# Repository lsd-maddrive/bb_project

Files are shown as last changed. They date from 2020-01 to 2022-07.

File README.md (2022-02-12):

# BB-ka project

<div align="center">






</div>

Проект под командной разработкой, направленный на создание прикольной зверюхи a-ля BB-8 Звёздных войн, но с блэкджеком и силовыми драйверами.

<p align=center>
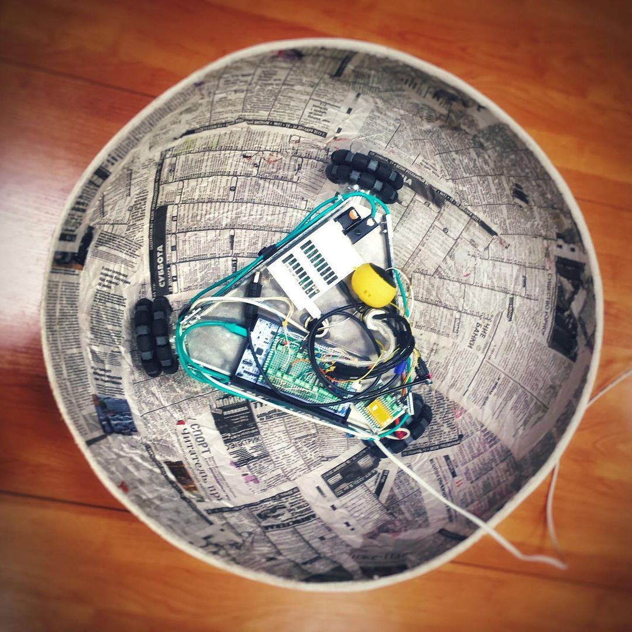
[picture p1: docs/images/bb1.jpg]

</p>

## Системные требования

- Версия Python: 3.8
- Операционная система: Ubuntu 20.04

## Настройка проекта

1. Установка 'make'

    * Windows - Установите [chocolatey](https://chocolatey.org/install) и установите 'make' командой:
    ```
    choco install make
    ```
    * Linux
    ```
    sudo apt-get install build-essential
    ```

2. Установите Python 3.8
    * Windows - Установите с [официального сайта](https://www.python.org/downloads/)
    * Linux
    ```
    sudo apt install python3.8-dev
    ```
3. Установите `poetry`
   * Windows - Используйте [официальные инструкции](https://python-poetry.org/docs/#windows-powershell-install-instructions) или команду powershell:
   ```
   (Invoke-WebRequest -Uri https://raw.githubusercontent.com/python-poetry/poetry/master/get-poetry.py -UseBasicParsing).Content | python -
   ```
   * Linux
    ```
    make poetry-download
    ```
4. Установите форматтеры и другие инструменты для разработки
    ```
    make tools-install
    ```
5. При работе с Jupyter-ноутбуками используйте виртуальное окружение, созданное `poetry` - `.venv`

## Полезные ссылки

* [F767ZI Reference manual (RM)](http://www.st.com/content/ccc/resource/technical/document/reference_manual/group0/96/8b/0d/ec/16/22/43/71/DM00224583/files/DM00224583.pdf/jcr:content/translations/en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)
* [F767ZI Datasheet (DS)](http://www.st.com/content/ccc/resource/technical/document/datasheet/group3/c5/37/9c/1d/a6/09/4e/1a/DM00273119/files/DM00273119.pdf/jcr:content/translations/en.DM0027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)
* [F767ZI Nucleo pinout](https://os.mbed.com/platforms/ST-Nucleo-F767ZI/)
---
* [F767ZI Alternate functions](http://www.st.com/content/ccc/resource/technical/document/datasheet/group3/c5/37/9c/1d/a6/09/4e/1a/DM00273119/files/DM00273119.pdf/jcr:content/translations/en.DM0027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)
* [F767ZI Pins assignment (+analogs)](http://www.st.com/content/ccc/resource/technical/document/datasheet/group3/c5/37/9c/1d/a6/09/4e/1a/DM00273119/files/DM00273119.pdf/jcr:content/translations/en.DM0027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)
* [F767ZI Timer triggers](http://www.st.com/content/ccc/resource/technical/document/reference_manual/group0/96/8b/0d/ec/16/22/43/71/DM00224583/files/DM00224583.pdf/jcr:content/translations/en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)

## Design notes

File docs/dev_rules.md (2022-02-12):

Привет, разработчик!
Здесь будут перечислены некоторые правила, которых стоит придерживаться для создания единого стиля разработки =)

* Оформление функций в соответствии со стилем `CamelCase` [`breakSensorIsPressed()`] или через `snake_case` [`break_sensor_is_pressed()`].

* Комментарии к функциям устанавливаются в соответствии с
[Doxygen стилем](https://www.rosettacommons.org/docs/latest/development_documentation/tutorials/doxygen-tips) / [Еще](https://www.stack.nl/~dimitri/doxygen/manual/commands.html)
Например
```c++
/*
 * @brief       This function makes something good
 * @param [in]  val  Motor power value [0-100]
 */

```
или
```c++
/**
 * Brief description of method
 * @pre
 *    Any preconditions that this method requires
 * @post
 *    Any postconditions that result because of this method
 * @param [0, n-1] paramName
 *    Brief description of parameter
 * @return
 *    Brief description of return value
 * @throw
 *    An EXPLICIT throw specification - including which guarantee it offers (basic, strong, nothrow)
 *    and WHY the various exceptions may be thrown.
 */
```

* Комментарии к переменным можно снабжать однострочными комментариями, желательно на строке, предшествующей определению переменной
```c++
/* Encoder tick count, should be limited by range [-1000; 1000] */
int16_t ticks = 0;

```

* Каждый модуль должен снабжаться заголовочным файлом с набором данных, которые отображают, что можно использовать в других модулях (открытые прототипы и структуры)

```c++
/* Header content */
#ifndef HEADER_NAME_H_
#define HEADER_NAME_H_

typedef struct
{
    /* Absolute value of accelerometer range */
    uint32_t accel_range;

    /* Absolute value of gyroscope range */
    uint32_t gyro_range;

} imu_conf_t;

/* 32 bits - *100 multiplier encoded float value */
/* 3245 <- 32.45 accel value */
typedef int32_t imu_accel_val_t;

/**
 * @brief
 *      Initialize and start IMU driver
 * @param   conf
 *      Pointer to configuration structure
 * @return
 *      EOK     - ok
 *      EFAULT  - failed to initialize
 */
int imu_start(imu_conf_t *conf);

/**
 * @brief
 *      Get IMU acceleration value by axis X
 * @param   out_x_val
 *      Referenced value of X acceleration to be written
 * @return
 *      EOK     - ok
 *      EFAULT  - failed calculation
 *      EIO     - reading failed
 */
int imu_get_accel_x(imu_accel_val_t *out_x_val);

...

#endif // HEADER_NAME_H_
```

* Отступы (indents) должны иметь размер 4 пробела (не табуляция) [редакторы могут заменять нажатие Tab на необходимый отступ]

* Определение типов задается по шаблону `<название типа>_t`, например, `breakPower_t`

* Любой разрабатываемый модуль должен проходить стадию разработки, тестирования и добавления в основную ветку (develop). В ветку мастер (master) добавляются только версии со 100% рабочими изменениями при согласии всех разработчиков.

* Тестирование должно проводиться в отдельно разработанном приложении с минимальным количеством кода при максимально использовании модуля. Постарайтесь как можно разносторонне проверить модуль =). Для примера, проверка сенсора может производиться путем периодического чтения данных и вывода в последовательный порт форматированным выводом. Само тестирование предполагает изменение условий сенсора и проверка вывода.

* В комментарии к коммиту указывается название ветки или название разрабатываемого модуля. Для общих исправлений используется тэг `[common]`.
```bash
git commit -am '[frontWheel]: New prototype for: int direction_get_value(dirVal_t *out_value);'

```

* При закрытии issue необходимо указывать коммент, в котором были сделаны последние изменения по теме issue.
```bash
git commit -am '[directionDriver]: Fixed #34'

```
* При разрешении issue необходимо присваивать работу над ним себе (если оно ранее уже не было присвоено), тем самым вы обозначите, что вы берётесь зе его исправление. Кроме того, по возможности необходимо классифицировать его с помощью лейбла:
- enchancement (нововведедние / предложение)
- bug
- help wanted
- duplicate
- good first issue
- invalid

---
Просто некоторые заметки:

* Хороший гайд по ведению веток: http://nvie.com/posts/a-successful-git-branching-model

* Для добавления собственного модуля необходимо добавить указания `.c` файлов в project.mk.

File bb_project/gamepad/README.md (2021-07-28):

# How to deal with Xbox joystick 

1. Check available software

```bash
sudo apt-get update
sudo apt-get upgrade
```

2. Install xow driver 

* 2.1. Install libusb

```bash
sudo apt-get install libusb-1.0-0-dev
```

* 2.2. Install cabextract

```bash
sudo apt-get install cabextract
```

* 2.3. Follow the original [README](https://github.com/medusalix/xow)

3. Install all required modules

```bash
pip3 install -r requirements.txt
```

4. Run python-script 

```bash
python3 gamepad.py 
```

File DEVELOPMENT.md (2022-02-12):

# Development guide

This is guide how to prepare development environment and use main tools

## Table of contents

- [Table of contents](#table-of-contents)
- [Preparations](#preparations)
- [Optional setup steps](#optional-setup-steps)
- [Some known issues](#some-known-issues)

## Preparations

1. Install make
    - Windows:

        Install [chocolatey](https://chocolatey.org/install) and install `make` with command:

    ```powershell
    choco install make
    ```

    - Linux:

    ```bash
    sudo apt-get install build-essential
    ```

1. Install python 3.8
    - Windows

        Install with [official executable](https://www.python.org/downloads/)

    - Linux

    ```bash
    sudo apt install python3.8-dev
    ```

1. Install poetry

   - Windows

        Use [official instructions](https://python-poetry.org/docs/#windows-powershell-install-instructions) or use `powershell` command:

    ```powershell
    (Invoke-WebRequest -Uri https://raw.githubusercontent.com/python-poetry/poetry/master/get-poetry.py -UseBasicParsing).Content | python -
    ```

   - Linux

    ```bash
    make poetry-download
    ```

2. Initialize poetry and install `pre-commit` hooks:

```bash
make install
```

[Table of contents](#table-of-contents)

## Optional setup steps

1. Install VSCode Extensions
   - [EditorConfig for VS Code](https://marketplace.visualstudio.com/items?itemName=EditorConfig.EditorConfig)
      Open control panel (Ctrl+P) and enter `ext install EditorConfig.EditorConfig`

1. To initialize generation of Table of Contents from notebook headers we use `nbextension`:

    - `nbextention-toc-install`

    > It is required version nbconvert~=5.6.1 (checked for date 2021-12-29)

    - To export notebook with ToC use next command:

      ```bash
      poetry run jupyter nbconvert --template toc2 --to html_toc --output-dir ./exports <путь до файла>
      ```

      > For example, `poetry run jupyter nbconvert --template toc2 --to html_toc --output-dir ./exports notebooks/example.ipynb`

[Table of contents](#table-of-contents)

## Some known issues

- If you have issues with python version like:

    ```bash
    The currently activated Python version 3.9.7 is not supported by the project (~3.8.0)
    ...
    NoCompatiblePythonVersionFound
    ...
    ```

    Check version of your `python3` binary and make sure you have python3.8 installed.

[Table of contents](#table-of-contents)

Некоторые [правила оформления](https://github.com/serykhelena/bb-8_project/blob/develop/controller_bb_8_driver/docs/dev_rules.md)

## Как изменить код на винде, но прошить через малину

1. После того, как проект собран - запустить батник `move_bin.bat` - он переместит файл `ch.bin` в расшаренную папку (убедитесь, что она есть и креды правильные, иначе доступа не будет).

2. В малине запустить скрипт `pi_load_stm.sh`

```bash
./pi_load_stm.sh
```
[Table of contents](#table-of-contents)

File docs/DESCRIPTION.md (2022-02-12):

# Описание проекта BB-ka

Проект под командной разработкой, направленный на создание прикольной зверюхи a-ля BB-8 из Звёздных войн, но с блэкджеком и силовыми драйверами.

<p align=center>

</p>

## Статьи

### 2021

* [Spherical Robot Remote Control Development](https://ieeexplore.ieee.org/document/9460236)
* [Design and Implementations of Spherical Robot Hardware Level](https://ieeexplore.ieee.org/document/9396257)

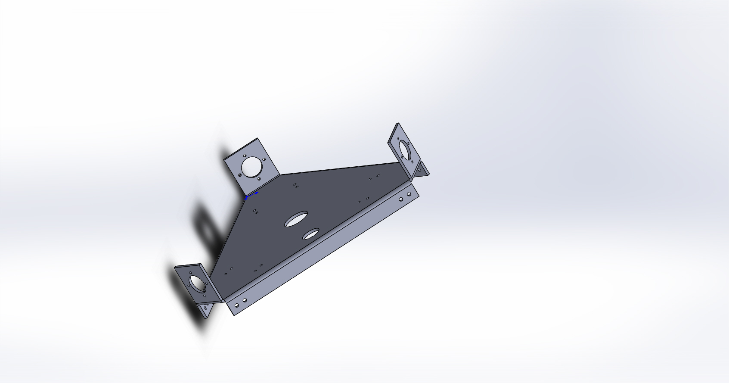
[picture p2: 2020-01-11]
Чертежи/Платформы/Для изготовления/Нижняя платформа.JPG

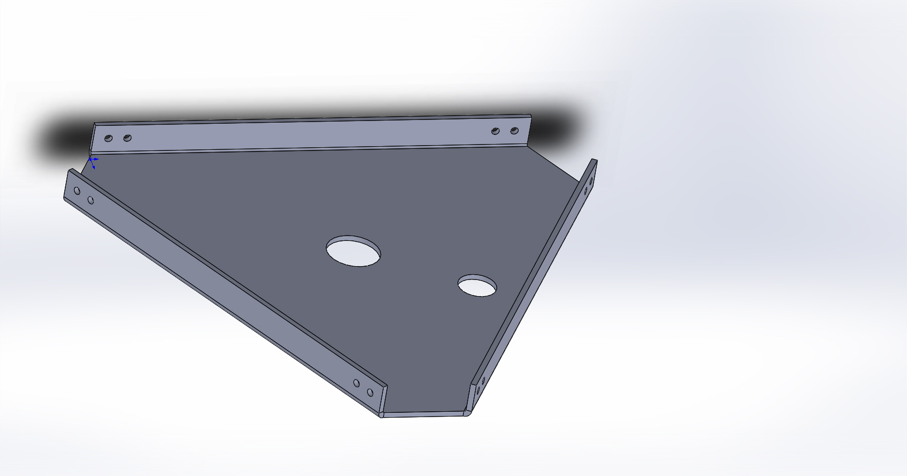
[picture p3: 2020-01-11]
Чертежи/Платформы/Для изготовления/Верхняя платформа.JPG

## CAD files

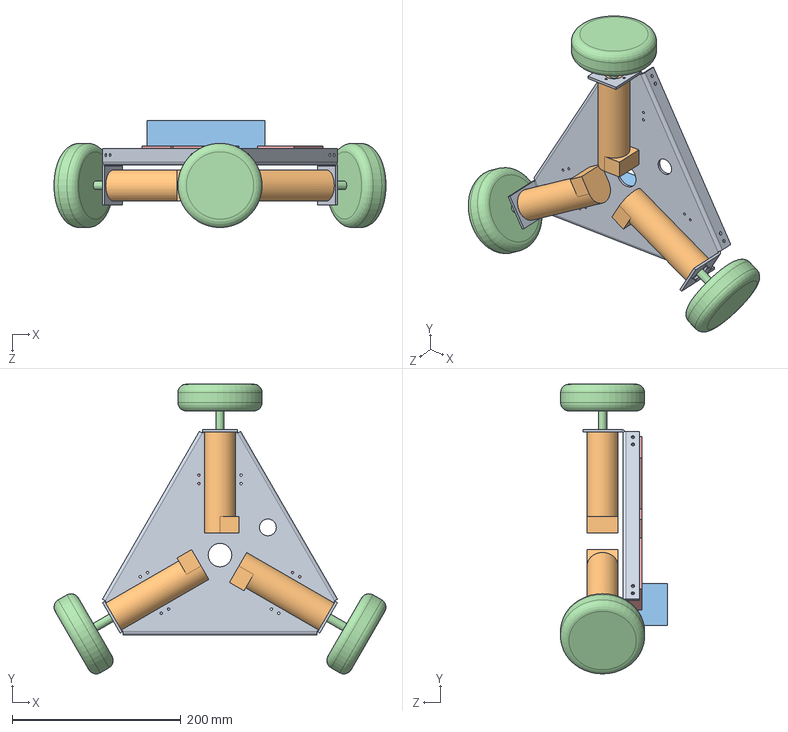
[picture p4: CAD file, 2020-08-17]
Чертежи/Платформы/Сборка1.SLDASM
394.0 x 344.0 x 126.9 mm
Нижняя платформа
Motor x 3
батарейка
Колесо x 3
Драйвер x 3

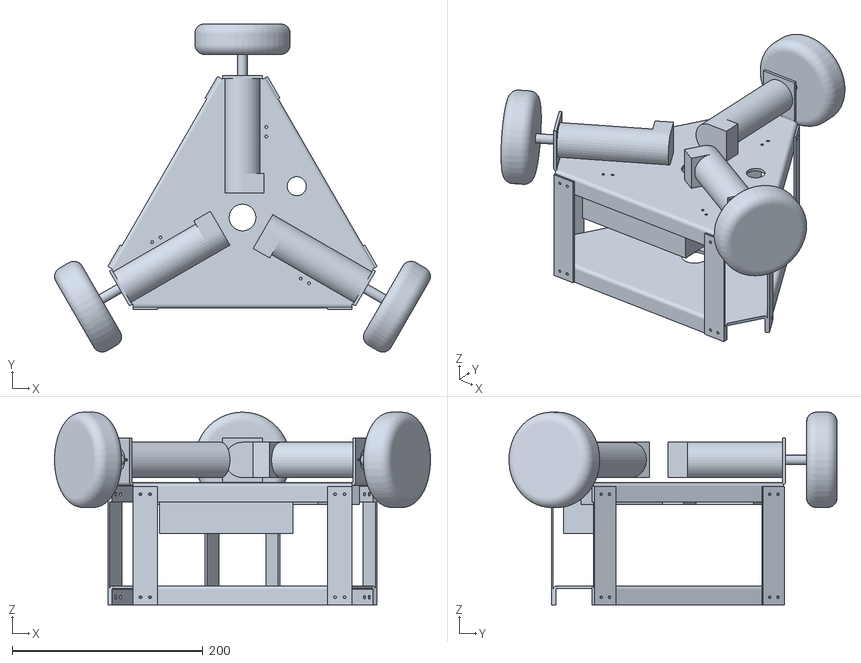
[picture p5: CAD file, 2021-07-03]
matlab/Real-time orientation/platform.STL
394.1 x 344.0 x 202.0

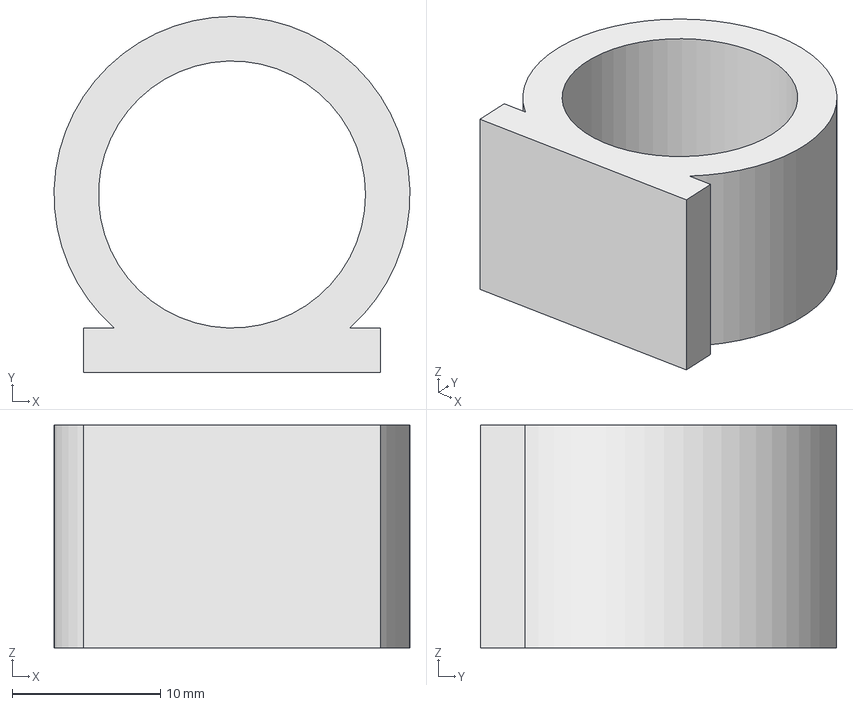
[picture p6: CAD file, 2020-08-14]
Чертежи/freeCAD/small_wires.FCStd
24.0 x 24.0 x 15.0 mm

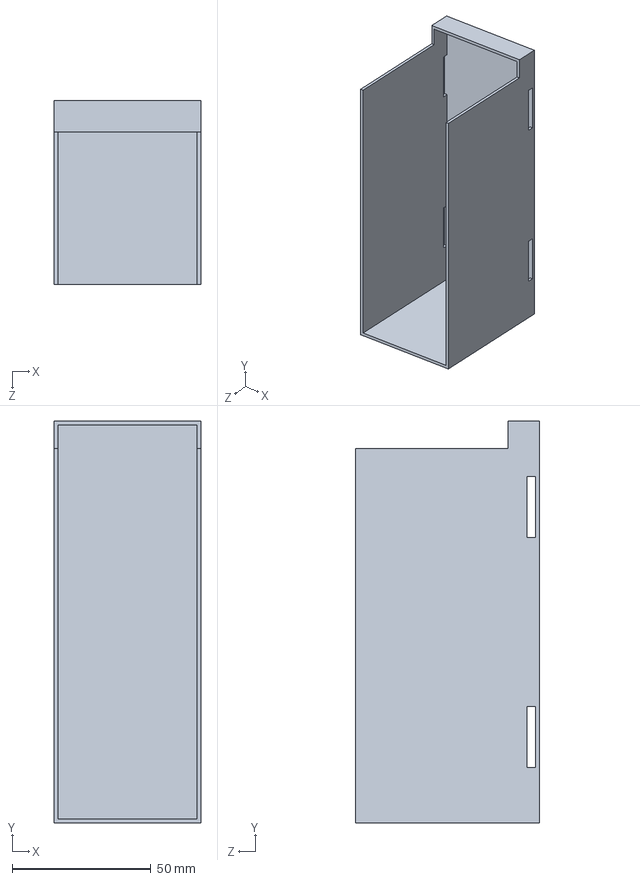
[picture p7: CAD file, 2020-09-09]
Чертежи/solid/Крепление батареек.SLDPRT
53.0 x 145.0 x 66.5 mm

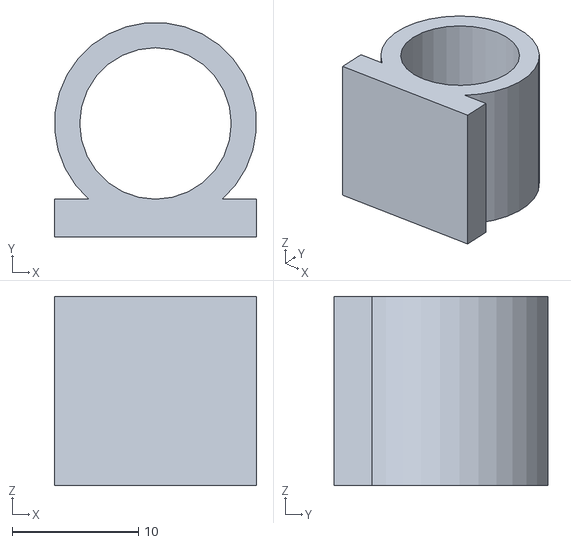
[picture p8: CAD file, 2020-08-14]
Чертежи/stl/additional_sugar/small_wires.stl
16.0 x 17.0 x 15.0

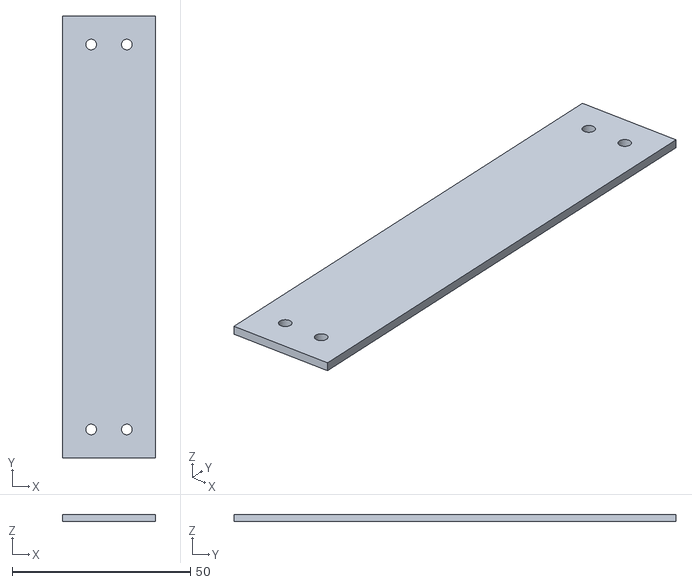
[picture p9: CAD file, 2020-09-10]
Чертежи/stl/Полоска.STL
26.0 x 124.0 x 2.00

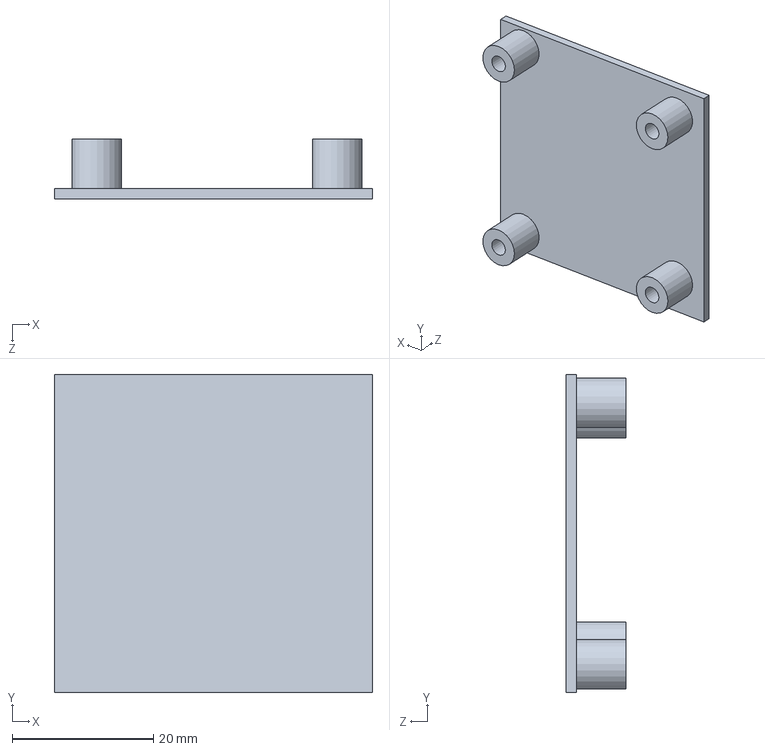
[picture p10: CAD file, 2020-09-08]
Чертежи/solid/Крепление гироскопа.SLDPRT
45.0 x 45.0 x 8.50 mm

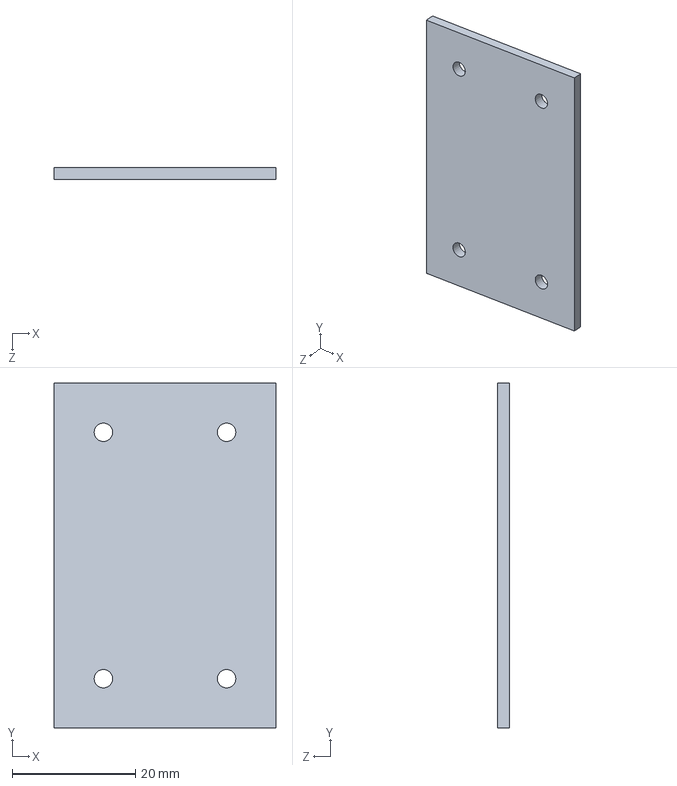
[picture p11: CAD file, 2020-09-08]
Чертежи/Платформы/Крепеж для верхней платформы.SLDPRT
36.0 x 56.0 x 2.00 mm

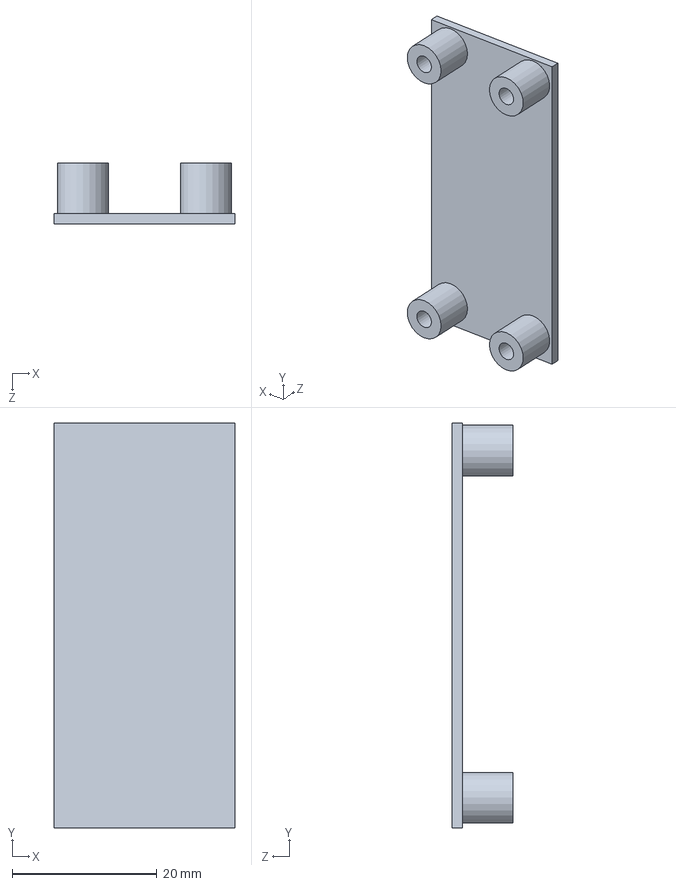
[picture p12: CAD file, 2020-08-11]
Чертежи/solid/Крепление переходника 2S.SLDPRT
25.0 x 56.0 x 8.50 mm

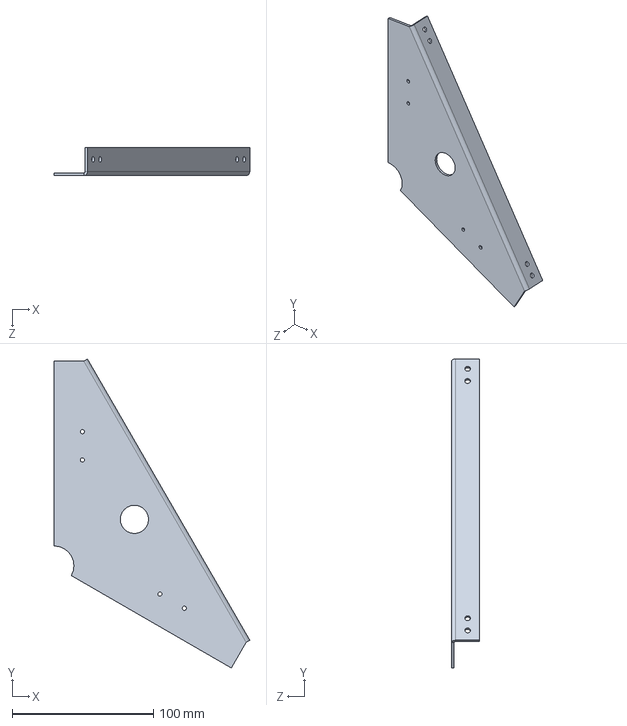
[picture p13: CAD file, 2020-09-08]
Чертежи/Платформы/Верхняя платформа part2.SLDPRT
138.6 x 218.9 x 20.0 mm

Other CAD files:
Чертежи/Платформы/Для изготовления/Полоска.DWG
Чертежи/Платформы/Полоска.SLDPRT
Чертежи/freeCAD/big_wires.FCStd
Чертежи/stl/additional_sugar/big_wires.stl
Чертежи/stl/Крепление батареек.STL
Чертежи/Платформы/Для изготовления/Нижняя платформа Линии сгиба.DWG
Чертежи/stl/Крепеж для верхней платформы (x3).STL
Чертежи/Платформы/Для изготовления/Нижняя платформа Резка.DWG
Чертежи/solid/Крепление драйвера.SLDPRT
Чертежи/solid/Крепление переходника 4S.SLDPRT
Чертежи/stl/Верхняя платформа part1 (x2).STL
Чертежи/stl/Верхняя платформа part2.STL
Чертежи/stl/Крепление гироскопа.STL
Чертежи/stl/Крепление драйвера.STL
Чертежи/stl/Крепление переходника 2S.STL
Чертежи/stl/Крепление переходника 4S.STL
Чертежи/Платформы/Motor.SLDPRT
Чертежи/Платформы/Верхняя платформа (для разделения).SLDPRT
Чертежи/Платформы/Верхняя платформа 2.SLDPRT
Чертежи/Платформы/Верхняя платформа part1.SLDPRT
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

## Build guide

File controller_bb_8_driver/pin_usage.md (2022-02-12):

# Использование модулей периферии контроллера

## Tickless mode => GPT5

## Отладка UART

Driver | Pins | Input/Output
:-----:|:----:|:------------:
SD6    | PG_14| TX
SD6    | PG_9 | RX

## Драйвер управления приводами движения

### Motor A
Driver | Pins | Input/Output | Name
:-----:|:----:|:------------:|:--------:
PWM1   | PE_11| output (channel 2) | HIN1
PWM1   | PE_10| output (channel 2N)| LIN1
PWM1   | PE_13| output (channel 3) | HIN2
PWM1   | PE_12| output (channel 3N)| LIN2

### Motor B
Driver | Pins | Input/Output | Name
:-----:|:----:|:------------:|:--------:
PWM8   | PC_6 | output (channel 1) | HIN1
PWM8   | PA_5 | output (channel 1N)| LIN1
PWM8   | PC_7 | output (channel 2) | HIN2
PWM8   | PB_0 | output (channel 2N)| LIN2

### Motor C
Driver | Pins | Input/Output | Name
:-----:|:----:|:------------:|:--------:
PWM8   | PC_8 | output (channel 3) | HIN1
PWM8   | PB_1 | output (channel 3N)| LIN1
PWM1   | PE_9 | output (channel 1) | HIN2
PWM1   | PE_8 | output (channel 1N)| LIN2

## Драйвер обработки энкодера

### Encoder Motor A
Driver | Pins | Input/Output | Base EXT channel
:-----:|:----:|:------------:|:--------:
EXT1   | PD_5 | input | YES
EXT1   | PD_4 | input | NO

### Encoder Motor B
Driver | Pins | Input/Output | Base EXT channel
:-----:|:----:|:------------:|:--------:
EXT1   | PD_7 | input | YES
EXT1   | PD_6 | input | NO

### Encoder Motor C
Driver | Pins | Input/Output | Base EXT channel
:-----:|:----:|:------------:|:--------:
EXT1   | PD_3 | input | YES
EXT1   | PE_2 | input | NO

## Драйвер для обработки гироскоп

Driver | Pins | Input/Output
:-----:|:----:|:------------:
i2c    | PB_8 | SCL
i2c    | PB_9 | SDA

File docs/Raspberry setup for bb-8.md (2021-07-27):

## Samba (local folder)

Install samba and edit .conf file

>sudo apt-get install samba samba-common-bin
>
>sudo nano /etc/samba/smb.conf

change file by altering/adding:

>workgroup = WORKGROUP
>
>wins support = yes
>
>[PiShare]
>
>comment=Raspberry Pi Share
>
>path=/home/pi/share
>
>browseable=Yes
>
>writeable=Yes
>
>only guest=no
>
>create mask=0777
>
>directory mask=0777
>
>public=no

create password

>sudo smbpasswd -a pi

Create *share* folder and start service

>mkdir ~/share
>
>sudo service smbd restart

## Change password

>passwd

follow instructions. If need to set weak password (less then 6 symbol length):

>sudo -su
>
>passwd pi
>
>exit

## turn on VNC

>sudo apt update
>
>sudo apt install realvnc-vnc-server realvnc-vnc-viewer
>
>sudo raspi-config

Go to interfacing options -> VNC -> set yes

>ifconfig

Remember ip adress! You will need it to connect via any VNC viewer from other device

## wi-fi setup

Edit interfaces file

>sudo nano /etc/network/interfaces

Edit file by adding next lines

>auto lo
>
>iface lo inet loopback
>
>iface eth0 inet manual
>
>auto wlan0
>
>allow-hotplug wlan0
>
>iface wlan0 inet manual
>
>wpa-roam /etc/wpa_supplicant/wpa_supplicant.conf

Edit wpa_supplicant file

>sudo nano /etc/wpa_supplicant/wpa_supplicant.conf

File should have 2 lines: ctrl_interface... and update_config=1
Add Router settings. No extra spaces!

>network={
>
>ssid="NETWORK NAME"
>
>psk="NETWORK PASS"
>
>}

Reboot and check if it works. If no try next:
>sudo ip link set wlan0 down
>
>sudo ip link set wlan0 up
>
>
>sudo wpa_supplicant -B -iwlan0 -c /etc/wpa_supplicant/wpa_supplicant.conf -Dnl80211,wext
>
>sudo dhclient wlan0

## Set static ip

Edit dgcpcd file

sudo nano /etc/dhcpcd.conf

Type this at the end of file:

>nodhcp
>
>interface wlan0
>
>static ip_address=DISIRED IP/24
>
>static routers=ROUTER IP
>
>static domain_name_servers=USUALLY SAME AS ROUTER IP

## Voice sinthesis

Install espeak-ng module

>sudo apt-get install espeak-ng

You can check if it works by calling

>espeak-ng test

Make shure you have audio device to hear. Check if audio output is set to analog out, not hdmi

## Xbox gamepad driver

Install some modules

>sudo apt-get curl
>
>sudo apt-get cabextract
>
>sudo apt-get libusb-1.0-0-dev
>
>sudo apt-get systemd

Download and install xow driver

>git clone https://github.com/medusalix/xow
>
>cd xow
>
>make BUILD=RELEASE
>
>sudo make install
>
>sudo systemctl enable xow
>
>sudo systemctl start xow

## Prepare for bb

Clone bb repository

>git clone https://github.com/serykhelena/bb-8_project.git
>
>cd /bb-8_project/python
>
>pip3 install virtualenv
>
>python3 -m venv venv
>
>source venv/bin/activate
>
>pip3 install -r requirements.txt

# Enjoy!

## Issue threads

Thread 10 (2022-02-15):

Вибрация геймпада

Doraepod, 2022-02-15:
Геймпад умеет вибрировать и зачатки даже есть в текущей версии обертки. Это можно использовать для оперативно сигнализирования о чем-либо. Например, недопустимый наклон робота, севшая батарейка, окончание инициализации...

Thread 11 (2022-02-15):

Протокол общения малины с МК

Doraepod, 2022-02-15:
Для передачи более сложных команд и запросов с верхнего уровня надо придумать формат посылки и способ его обработки. Для надежности можно прикрутить контрольную сумму.

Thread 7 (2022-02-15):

Задатчик скорости

Doraepod, 2022-02-15:
Ограничить скорость изменения скорости для более плавного движения. Сейчас при старте могут проскальзывать колеса, что приводит к заносам. Ограничить скорость можно для самих движков или для задания на скорость поступательного движения. В первом случае может возникнуть некорректное движения из-за несоответствия распределения скоростей по движкам кинематике заданного движения. Ограничение должно задаваться максимальным ускорением в единицах м/с^2 или об/с^2.

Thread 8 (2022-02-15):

Оценка заряда батареи

Doraepod, 2022-02-15:
Придумать способ оценить уровни зарядов батарей и передать на МК/малину. Либо найти готовое устройство, или разработать плату самостоятельно. При отключенном питании устройство не должно потреблять ток.

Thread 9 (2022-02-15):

Замена гиросокопа на IMU

Doraepod, 2022-02-15:
Гироскоп не позволяет корректно оценить ориентацию при любом отклонении от горизонтального положения. Есть разработанная плата с гироскопом+акселерометром+магнитометром работающими аналогично текущему варианту. Можно использовать фильтр Маджвика, как свою реализацию, так и оригинальную, доступную в исходном коде.

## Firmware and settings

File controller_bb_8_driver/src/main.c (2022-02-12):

#include "tests.h"


static inline void testsRoutines( void )
{
#if (MAIN_PROGRAM_ROUTINE == PROGRAM_MOTOR_DIRECTION_TEST)

    testRawMotorDirectionControlRoutine( );

#elif (MAIN_PROGRAM_ROUTINE == PROGRAM_MOTOR_RAW_CONTROL_TEST)

    testRawMotorControlRoutine( );

#elif (MAIN_PROGRAM_ROUTINE == PROGRAM_MOTOR_PRC_CONTROL_TEST)

    testMotorControlRoutine( );

#elif (MAIN_PROGRAM_ROUTINE == PROGRAM_ENCODER_TEST )

    testEncoderRoutine( );

#elif (MAIN_PROGRAM_ROUTINE == PROGRAM_MOTOR_MATLAB_FREQ_TEST )

    testMatlabFrequency();

#elif (MAIN_PROGRAM_ROUTINE == PROGRAM_MOTOR_SPEED_TEST )

    testMotorSpeed();

#elif (MAIN_PROGRAM_ROUTINE == PROGRAM_WHEEL_SPEED_TEST )

    testWheelSpeed();

#elif (MAIN_PROGRAM_ROUTINE == PROGRAM_LINEAR_SPEED_MATLAB_TEST )

    testLinearSpeedMatlab();

#elif (MAIN_PROGRAM_ROUTINE == PROGRAM_ROBOT_ODOMETRY_TEST )

    testRobotOdometry();

#elif (MAIN_PROGRAM_ROUTINE == PROGRAM_WHEEL_CONTROL_MATLAB )

    testWheelControlMatlab();

#elif (MAIN_PROGRAM_ROUTINE == PROGRAM_ONE_WHEEL_CONTROLLER_MATLAB)

    testOneWheelControllerMatlab();

#elif (MAIN_PROGRAM_ROUTINE == PROGRAM_JOYSTICK_TEST )

    testJoystick();

#elif ( MAIN_PROGRAM_ROUTINE == PROGRAM_ROBOT_WITH_JOYSTICK_TEST )

    testRobotWithJoystick();

#elif (MAIN_PROGRAM_ROUTINE == PROGRAM_GYROSCOPE_TEST)

    testGyroscope();

#elif (MAIN_PROGRAM_ROUTINE == PROGRAM_LOGGER_TEST)

    testLogger();

#endif
}

int main(void)
{
    chSysInit();
    halInit();

    #if (MAIN_PROGRAM_ROUTINE != PROGRAM_ROUTINE_MASTER)

        testsRoutines();

    #else
        mainUnitsInit();
    #endif
}

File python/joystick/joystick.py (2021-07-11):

import logging

logging.basicConfig(
    level=logging.DEBUG, format="%(asctime)s - %(name)s - %(levelname)s - %(message)s"
)
logger = logging.getLogger(__name__)

import math
import asyncio
import serial
import struct
from src.xbox_one import Joystick
from src.robot_logging import CsvLogger
from src.tcp import TcpLog
from datetime import datetime
from datetime import timedelta

from src.config import V_MAX, ANG_SPEED_MAX, START_BYTES, TCP_FLAG
from utils import calc_angle, calc_velocity, calc_angle_speed


def handle_package(port, csv_logger, tcp_client):
    """
    Reading of data from mcu. If everything is fine, save it to csv and send via tcp to matlab
    :param port: Serial port to read. Need to do because of async: can't see from outer space
    :param csv_logger: logger class exemplar. Need to do because of async: can't see from outer space
    :param tcp_client: tcp client class exemplar. Need to do because of async: can't see from outer space
    """
    package = port.read(56)
    if [package[i] for i in range(3)] == START_BYTES:
        if package[3] == 1:
            csv_logger.flush()
            csv_logger.new_file()
        elif package[3] == 0:
            csv_logger.log_line(package[4:])
        if tcp_client is not None:
            tcp_client.send(package[12:24])
    port.reset_input_buffer()


async def wait_until(dt):
    """
    Wait until desired datetime. If the datetime is in the past, return immediately.
    :param dt: datetime to wait until
    """
    now = datetime.now()
    delta = (dt - now).total_seconds()
    if delta > 0:
        await asyncio.sleep(delta)


async def robot_control(csv_logger):
    try:
        joy = 0
        port = 0
        port = serial.Serial("/dev/ttyACM0", 115200)
        logger.debug("USB is connected")
        if TCP_FLAG:
            tcp_client = TcpLog("192.168.90.101", 8081)
            tcp_client.open()
        else:
            tcp_client = None

        # Instantiate the controller
        joy = Joystick()

        # Maybe not necessary. Gamepad store old values for some reason. Maybe only 360
        # await asyncio.sleep(3)

        logger.debug("Connected to %s", joy.device.name)

        port.write(struct.pack("B", 185))

        time = datetime.now()
        while joy.leftTrigger() < 0.8:

            time = time + timedelta(milliseconds=100)

            ang_speed = calc_angle_speed(joy.rightYAxis(), ANG_SPEED_MAX)

            velocity_x, velocity_y = calc_velocity(
                joy.leftXAxis(), joy.leftYAxis(), joy.rightTrigger(), V_MAX
            )
            # Usart data transmit
            port.write(
                struct.pack(
                    "<fff", float(velocity_x), float(velocity_y), float(ang_speed)
                )
            )
            handle_package(port, csv_logger, tcp_client)

            await wait_until(time)

    except (FileNotFoundError, serial.serialutil.SerialException):
        logger.error("USB port is not correct. Connection failed!")
    except AttributeError:
        # to avoid exception in joy.close()
        joy = 0
        logger.error("Joystick is turned off. Check it, please!")
    except OSError:
        logger.error("Joystick fell asleep!")
    finally:
        csv_logger.stop()
        # Close out when done
        if joy != 0:
            joy.close()
            logger.debug("Joystick is closed successfully")
        if port != 0:
            port.close()
            logger.debug("Serial port is closed successfully")


async def log(csv_logger):
    while csv_logger.run:
        csv_logger.flush()
        await asyncio.sleep(5)


def main():
    csv_logger = CsvLogger("Logs")
    loop = asyncio.get_event_loop()
    tasks = [
        loop.create_task(robot_control(csv_logger)),
        loop.create_task(log(csv_logger)),
    ]
    loop.run_until_complete(asyncio.wait(tasks))
    loop.close()


if __name__ == "__main__":
    main()

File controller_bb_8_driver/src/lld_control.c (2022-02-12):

#include <lld_control.h>

/*============================================================================*/
/* PWM CONFIGURATION PINS                                                     */
/*============================================================================*/

/**************** MOTOR 1 (PWM 1) ********************/
#define MOTOR1_PWM1CH_HIN1      1
#define MOTOR1_PE11_ACTIVE      PWM_OUTPUT_ACTIVE_HIGH
#define MOTOR1_PE11_DISABLE     PWM_OUTPUT_DISABLED
#define MOTOR1_PWM_LINE_HIN1    PAL_LINE(GPIOE, 11)

#define MOTOR1_PWM1CH_LIN1      1  // N
#define MOTOR1_PWM_LINE_LIN1    PAL_LINE(GPIOE, 10)

#define MOTOR1_PWM1CH_HIN2      2
#define MOTOR1_PE13_ACTIVE      PWM_OUTPUT_ACTIVE_HIGH
#define MOTOR1_PE13_DISABLE     PWM_OUTPUT_DISABLED
#define MOTOR1_PWM_LINE_HIN2    PAL_LINE(GPIOE, 13)

#define MOTOR1_PWM1CH_LIN2      2  // N
#define MOTOR1_PWM_LINE_LIN2    PAL_LINE(GPIOE, 12)

/**************** MOTOR 2 (PWM 8) ********************/
#define MOTOR2_PWM8CH_HIN1      0
#define MOTOR2_PC6_ACTIVE       PWM_OUTPUT_ACTIVE_HIGH
#define MOTOR2_PC6_DISABLE      PWM_OUTPUT_DISABLED
#define MOTOR2_PWM_LINE_HIN1    PAL_LINE(GPIOC, 6)

#define MOTOR2_PWM8CH_LIN1      0  // N
#define MOTOR2_PWM_LINE_LIN1    PAL_LINE(GPIOA, 5)

#define MOTOR2_PWM8CH_HIN2      1
#define MOTOR2_PC7_ACTIVE       PWM_OUTPUT_ACTIVE_HIGH
#define MOTOR2_PC7_DISABLE      PWM_OUTPUT_DISABLED
#define MOTOR2_PWM_LINE_HIN2    PAL_LINE(GPIOC, 7)

#define MOTOR2_PWM8CH_LIN2      1  // N
#define MOTOR2_PWM_LINE_LIN2    PAL_LINE(GPIOB, 0)

/**************** MOTOR 3 (PWM1 + PWM8) ********************/
#define MOTOR3_PWM8CH_HIN1      2
#define MOTOR3_PC8_ACTIVE       PWM_OUTPUT_ACTIVE_HIGH
#define MOTOR3_PC8_DISABLE      PWM_OUTPUT_DISABLED
#define MOTOR3_PWM_LINE_HIN1    PAL_LINE(GPIOC, 8)

#define MOTOR3_PWM8CH_LIN1      2  // N
#define MOTOR3_PWM_LINE_LIN1    PAL_LINE(GPIOB, 1)

#define MOTOR3_PWM1CH_HIN2      0
#define MOTOR3_PE9_ACTIVE       PWM_OUTPUT_ACTIVE_HIGH
#define MOTOR3_PE9_DISABLE      PWM_OUTPUT_DISABLED
#define MOTOR3_PWM_LINE_HIN2    PAL_LINE(GPIOE, 9)

#define MOTOR3_PWM1CH_LIN2      0  // N
#define MOTOR3_PWM_LINE_LIN2    PAL_LINE(GPIOE, 8)


static PWMDriver    *pwm1Driver = &PWMD1;
static PWMDriver    *pwm8Driver = &PWMD8;

/*============================================================================*/
/* PWM CONFIGURATION STRUCTURES                                               */
/*============================================================================*/

PWMConfig pwm1conf = {
    .frequency = PWM_FREQ,
    .period    = PWM_PERIOD,
    .callback  = NULL,
    .channels  = {
                  {.mode = MOTOR3_PE9_ACTIVE  | PWM_COMPLEMENTARY_OUTPUT_ACTIVE_HIGH,    .callback = NULL},
                  {.mode = MOTOR1_PE11_ACTIVE | PWM_COMPLEMENTARY_OUTPUT_ACTIVE_HIGH,    .callback = NULL},
                  {.mode = MOTOR1_PE13_ACTIVE | PWM_COMPLEMENTARY_OUTPUT_ACTIVE_HIGH,    .callback = NULL},
                  {.mode = PWM_OUTPUT_DISABLED,     .callback = NULL}
                },
    .cr2        = 0,
    .bdtr       = 500,    // break && dead-time HOW TO CONTROL YOU?????
    .dier       = 0
};


PWMConfig pwm8conf = {
    .frequency = PWM_FREQ,
    .period    = PWM_PERIOD,
    .callback  = NULL,
    .channels  = {
                  {.mode = MOTOR2_PC6_ACTIVE | PWM_COMPLEMENTARY_OUTPUT_ACTIVE_HIGH,    .callback = NULL},
                  {.mode = MOTOR2_PC7_ACTIVE | PWM_COMPLEMENTARY_OUTPUT_ACTIVE_HIGH,    .callback = NULL},
                  {.mode = MOTOR3_PC8_ACTIVE | PWM_COMPLEMENTARY_OUTPUT_ACTIVE_HIGH,    .callback = NULL},
                  {.mode = PWM_OUTPUT_DISABLED,     .callback = NULL}
                },
    .cr2        = 0,
    .bdtr       = 500,    // break && dead-time HOW TO CONTROL YOU?????
    .dier       = 0
};

/*============================================================================*/
/* LOW-LEVEL FUCTIONS FOR DRIVE CONTROL                                       */
/*============================================================================*/

/**
 * @brief   Disable all used PWM channels
 */
static void lldDisableAllChannels( void )
{
    // Motor 1
    pwmDisableChannel( pwm1Driver, MOTOR1_PWM1CH_HIN1 );
    pwmDisableChannel( pwm1Driver, MOTOR1_PWM1CH_LIN1 );  // not working
    pwmDisableChannel( pwm1Driver, MOTOR1_PWM1CH_HIN2 );
    pwmDisableChannel( pwm1Driver, MOTOR1_PWM1CH_LIN2 );  // not working

    //Motor 2
    pwmDisableChannel( pwm8Driver, MOTOR2_PWM8CH_HIN1 );
    pwmDisableChannel( pwm8Driver, MOTOR2_PWM8CH_LIN1 );  // not working
    pwmDisableChannel( pwm8Driver, MOTOR2_PWM8CH_HIN2 );
    pwmDisableChannel( pwm8Driver, MOTOR2_PWM8CH_LIN2 );  // not working

    //Motor 3
    pwmDisableChannel( pwm8Driver, MOTOR3_PWM8CH_HIN1 );
    pwmDisableChannel( pwm8Driver, MOTOR3_PWM8CH_LIN1 );  // not working
    pwmDisableChannel( pwm1Driver, MOTOR3_PWM1CH_HIN2 );
    pwmDisableChannel( pwm1Driver, MOTOR3_PWM1CH_LIN2 );  // not working
}

/**
 * @brief   Configure all lines to be used for PWM
 */
static void lldConfigureLineMode( void )
{
    // Motor 1
    palSetLineMode( MOTOR1_PWM_LINE_HIN1, PAL_MODE_ALTERNATE(1) );
    palSetLineMode( MOTOR1_PWM_LINE_LIN1, PAL_MODE_ALTERNATE(1) );
    palSetLineMode( MOTOR1_PWM_LINE_HIN2, PAL_MODE_ALTERNATE(1) );
    palSetLineMode( MOTOR1_PWM_LINE_LIN2, PAL_MODE_ALTERNATE(1) );

    // Motor 2
    palSetLineMode( MOTOR2_PWM_LINE_HIN1, PAL_MODE_ALTERNATE(3) );
    palSetLineMode( MOTOR2_PWM_LINE_LIN1, PAL_MODE_ALTERNATE(3) );
    palSetLineMode( MOTOR2_PWM_LINE_HIN2, PAL_MODE_ALTERNATE(3) );
    palSetLineMode( MOTOR2_PWM_LINE_LIN2, PAL_MODE_ALTERNATE(3) );

    // Motor 3
    palSetLineMode( MOTOR3_PWM_LINE_HIN1, PAL_MODE_ALTERNATE(3) );
    palSetLineMode( MOTOR3_PWM_LINE_LIN1, PAL_MODE_ALTERNATE(3) );
    palSetLineMode( MOTOR3_PWM_LINE_HIN2, PAL_MODE_ALTERNATE(1) );
    palSetLineMode( MOTOR3_PWM_LINE_LIN2, PAL_MODE_ALTERNATE(1) );
}


static bool isInitialized   = false;

static float motor_b        = 0;
static float motor_k        = 0;


/**
 * @brief   Initialize periphery connected to driver control
 * @note    Stable for repeated calls
 */
void lldControlInit( void )
{
    if( isInitialized )
        return;

    motor_b = LLD_DUTY_MIN;
    motor_k = ( PWM_PERIOD - motor_b ) / 100;

    /*** PWM pins configuration ***/
    lldConfigureLineMode();

    pwmStart( pwm1Driver, &pwm1conf );
    pwmStart( pwm8Driver, &pwm8conf );

    // to avoid noise in contacts
    lldDisableAllChannels();

    isInitialized = true;
}
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

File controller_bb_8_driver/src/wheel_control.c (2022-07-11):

#include "wheel_control.h"

static virtual_timer_t  wheel_control_vt;

bool permeation_flag = false;

// Array for control values in percent for each of wheels
lldControlValue_t       wheelControlValuesPrc[3] = {0, 0, 0};
// Array for reference value of wheel speed [RPS]
wheelSpeedValue_t       wheelSpeedRefValuesPRS[3] = {0, 0, 0};

/**************** WHEEL A ********************/
wheelSpeedValue_t       wheelSpeedRefRPS_A    = 0;
// I-part with saturation
float                   wheelSpeedPrevError_A = 0;
float                   wheelSpeedIntg_A      = 0;

pidControllerValue_t    wheelController_A = {
    .kp = 50,
    .ki = 3,
    .kd = 0,
    .intgSaturation = LLD_MOTOR_MAX_PRC,
    .propDeadZone = 0,
    .controlDeadZone = 5
};

/**************** WHEEL B ********************/
wheelSpeedValue_t       wheelSpeedRefRPS_B    = 0;
float                   wheelSpeedPrevError_B = 0;
float                   wheelSpeedIntg_B      = 0;

pidControllerValue_t    wheelController_B = {
    .kp = 50,
    .ki = 3,
    .kd = 0,
    .intgSaturation = LLD_MOTOR_MAX_PRC,
    .propDeadZone = 0,
    .controlDeadZone = 5
};

/**************** WHEEL C ********************/
wheelSpeedValue_t       wheelSpeedRefRPS_C    = 0;
float                   wheelSpeedPrevError_C = 0;
float                   wheelSpeedIntg_C      = 0;

pidControllerValue_t    wheelController_C = {
    .kp = 50,
    .ki = 3,
    .kd = 0,
    .intgSaturation = LLD_MOTOR_MAX_PRC,
    .propDeadZone = 0,
    .controlDeadZone = 5
};


static void wheel_control_vt_cb( void *arg )
{
    arg = arg;  // to avoid warnings

/*============================================================================*/
/* Calculation Area                                                            */
/*============================================================================*/

    if( permeation_flag )
    {
/**************** CS WHEEL A ********************/
      odometrySpeedValue_t wheelSpeedRPS_A_LPF = odometryGetWheelSpeed( A, REVS_PER_SEC );
// P-Part
      float wheelSpeedError_A = wheelSpeedRefValuesPRS[0] - wheelSpeedRPS_A_LPF;
// I-Part
      wheelSpeedIntg_A += wheelController_A.ki * wheelSpeedError_A;
// I-part with saturation
      wheelSpeedIntg_A = CLIP_VALUE(
            wheelSpeedIntg_A,
            -wheelController_A.intgSaturation,
            wheelController_A.intgSaturation
      );
// D-Part [not used]
      float wheelSpeedDif_A = wheelSpeedError_A - wheelSpeedPrevError_A;

      wheelSpeedPrevError_A = wheelSpeedError_A;

      wheelControlValuesPrc[0] = wheelController_A.kp * wheelSpeedError_A +
                                 wheelSpeedIntg_A +
                                 wheelController_A.kd * wheelSpeedDif_A;

      if( abs(wheelControlValuesPrc[0]) <= wheelController_A.controlDeadZone )
      {
          wheelControlValuesPrc[0] = 0;
      }

/**************** CS WHEEL B ********************/
      odometrySpeedValue_t wheelSpeedRPS_B_LPF = odometryGetWheelSpeed( B, REVS_PER_SEC );
// P-Part
      float wheelSpeedError_B = wheelSpeedRefValuesPRS[1] - wheelSpeedRPS_B_LPF;
// I-Part
      wheelSpeedIntg_B += wheelController_B.ki * wheelSpeedError_B;
      wheelSpeedIntg_B = CLIP_VALUE(
            wheelSpeedIntg_B,
            -wheelController_B.intgSaturation,
            wheelController_B.intgSaturation
      );
// D-Part [not used]
      float wheelSpeedDif_B = wheelSpeedError_B - wheelSpeedPrevError_B;

      wheelSpeedPrevError_B = wheelSpeedError_B;

      wheelControlValuesPrc[1] = wheelController_B.kp * wheelSpeedError_B +
                                 wheelSpeedIntg_B +
                                 wheelController_B.kd * wheelSpeedDif_B;
      if( abs(wheelControlValuesPrc[1]) <= wheelController_B.controlDeadZone )
      {
          wheelControlValuesPrc[1] = 0;
      }

/**************** CS WHEEL C ********************/
      odometrySpeedValue_t wheelSpeedRPS_C_LPF = odometryGetWheelSpeed( C, REVS_PER_SEC );
// P-Part
      float wheelSpeedError_C = wheelSpeedRefValuesPRS[2] - wheelSpeedRPS_C_LPF;
// I-Part
      wheelSpeedIntg_C += wheelController_C.ki * wheelSpeedError_C;
      wheelSpeedIntg_C = CLIP_VALUE(
            wheelSpeedIntg_C,
            -wheelController_C.intgSaturation,
            wheelController_C.intgSaturation
      );
// D-Part [not used]
      float wheelSpeedDif_C = wheelSpeedError_C - wheelSpeedPrevError_C;

      wheelSpeedPrevError_C = wheelSpeedError_C;

      wheelControlValuesPrc[2] = wheelController_C.kp * wheelSpeedError_C +
                                 wheelSpeedIntg_C +
                                 wheelController_C.kd * wheelSpeedDif_C;

      if( abs(wheelControlValuesPrc[2]) <= wheelController_C.controlDeadZone )
      {
          wheelControlValuesPrc[2] = 0;
      }
/*============================================================================*/
/* Set control in percent                                                             */
/*============================================================================*/
      lldControlSetMotorPower( A, wheelControlValuesPrc[0] );
      lldControlSetMotorPower( B, wheelControlValuesPrc[1] );
      lldControlSetMotorPower( C, wheelControlValuesPrc[2] );
    }

    chSysLockFromISR();
    chVTSetI(&wheel_control_vt, TIME_MS2I( VT_WHEEL_CONTROL_MS ), wheel_control_vt_cb, NULL);
    chSysUnlockFromISR();
}

/**
 * @brief       Permeation is enabled,
 *              control system is enabled
 */
void wheelControlSetPermeation( void )
{
    permeation_flag = true;
}

/**
 * @brief       Permeation is disabled,
 *              control system is disabled
 */
void wheelControlResetPermeation( void )
{
    permeation_flag = false;
}

static bool isInitialized = false;

/**
 * @brief       Initialization of unit with control system for each wheel
 */
void wheelControlInit( void )
{
    if( isInitialized )
      return;

    lldControlInit( );
    odometryInit( );
    permeation_flag = false;

    chVTObjectInit(&wheel_control_vt);
    chVTSet( &wheel_control_vt, TIME_MS2I( VT_WHEEL_CONTROL_MS ), wheel_control_vt_cb, NULL );

    isInitialized = true;
}

/**
 * @brief       Set reference value of for specified wheel
 */
void wheelControlSetSpeed( wheelSpeedValue_t speed_val, motorNumberValue_t number, odometrySpeedUnit_t unit )
{
    speed_val = CLIP_VALUE( speed_val, WHEEL_SPEED_MIN_RPS, WHEEL_SPEED_MAX_RPS);

    switch( unit )
    {
        case REVS_PER_SEC:
            wheelSpeedRefValuesPRS[number] = speed_val;
            break;

        default:
            wheelSpeedRefValuesPRS[number] = 0; // temporary maybe
            break;
    }
}
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

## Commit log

2019-09-25 Test blueprints
    [Корпус STM.DWG, Корпус STM.SLDPRT, Крышка STM.DWG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]
2019-09-25 Drive
    http://gearmotor.ru/ig-32pgm.htm
    [Движок.SLDPRT, Каркас.SLDPRT, Корпус STM.SLDPRT]
2019-09-25 carcass + drive
    [Движок.SLDPRT, Каркас.SLDPRT]
2019-09-26 shock absorber
    [Движок.SLDPRT]
2019-09-28 solid try
    [Колесо.SLDPRT, Пластина.SLDPRT, Поршень.SLDPRT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]
2019-10-09 new try
    [Каркас + движок.SLDASM, Колесо.SLDPRT, Пластина (треугольная).SLDPRT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]
2019-10-10 triangle v0.9
    [Колесо.SLDPRT, Пластина (треугольная).SLDPRT, Полоска.SLDPRT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]
2019-11-17 Second breath
    [Motor.SLDPRT, Верхняя платформа.SLDPRT, Деталь1.SLDPRT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]
2019-11-21 first try to order
    [Motor.SLDPRT, Верхняя платформа 2.SLDPRT, Верхняя платформа Линии сгиба.DWG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]
2019-11-23 Marker holder v.2
    [Для маркеров 2.SLDPRT, Для маркеров.SLDPRT]
2020-01-14 Add tests for lld_control motor
2020-01-15 test for motor prc - used now
2020-01-21 Add speed calculation for motor (raw - revs/s)
2020-01-22 add code for all 3 motors, change Pe9 -> Pd15
2020-05-11 placement attempt
    [Драйвер.SLDPRT, Сборка1.SLDASM, батарейка.SLDPRT]
2020-07-24 errors - fixed, md - fixed, lld_control - not finished
    [lld_control.c, mcuconf.h, test_lld_control.c]
2020-07-24 not working, start fixing lld_control
    [common.h, lld_control.c]
2020-07-24 set and clear do not work T_T
    [common.h, lld_control.c, test_lld_control.c]
2020-07-29 need a lot of fixes
    [halconf.h, lld_control.c, mcuconf.h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]
2020-07-30 [lld_control] fixed errors, add complementary mode
    [lld_control.c, mcuconf.h, test_lld_control.c]
2020-07-30 [lld_control] tests - fixed
    [common.h, lld_control.c, test_lld_control.c]
2020-07-31 [lld_encoder] raw encoders - work, checked
2020-07-31 fix odometry tests amd module
    [common.h, lld_control.c, odometry.c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]
2020-07-31 some blueprints
    [Крепление батареек.SLDPRT, Крепление батареек.STL, Крепление драйвера.SLDPRT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]
2020-08-11 initial: test for motor freq
2020-08-11 Bluprints for battery adapters holders
    [Крепление переходника 2S.SLDPRT, Крепление переходника 2S.STL, Крепление переходника 4S.SLDPRT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]
2020-08-14 need to check test for freq
    [big_wires.FCStd, big_wires.stl, small_wires.FCStd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]
2020-08-15 Blueprints folder clean up
    [Motor.SLDPRT, Верхняя платформа 2.SLDPRT, Верхняя платформа Линии сгиба.DWG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]
2020-08-18 freq for pwm is choosen, bug with odometry - fixed
    [common.h, lld_encoder.c, odometry.c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]
2020-08-20 refactoring motor 1-3 to motor A-C, prepared LPF filter wheel speed
2020-08-20 python script is a little bit fixed
    [joystick.py]
2020-08-21 Wheel CS - initial
2020-08-21 test wheel CS
2020-08-21 need to fix wheel CS
    [test_wheel_control.c, wheel_control.c]
2020-08-24 test all wheels
2020-08-24 Scripts edited to operate 3 motors
2020-08-25 wheel control system is tuned, checked
2020-08-25 kinematic first test
2020-08-26 transfer kinematic from matlab to chibi - initial
2020-09-02 The first and only gyroscope test
2020-09-02 Interrupt not working
2020-09-03 VT for kinematic removed completely - tested
2020-09-04 add gyro to wheel control system, NOT checked!
2020-09-06 i2c added to pinusage
2020-09-08 Stl for gyroscope holder
    [Крепление гироскопа.SLDPRT, Крепление гироскопа.STL]
2020-09-08 Stl for upper platform
    [Верхняя платформа (для разделения).SLDPRT, Верхняя платформа part1 (x2).STL, Верхняя платформа part1.SLDPRT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]
2020-09-08 Upper platform fixation
    [Крепеж для верхней платформы (x3).STL, Крепеж для верхней платформы.SLDPRT]
2020-09-09 add folder
    [big_wires.stl, small_wires.stl, Крепление батареек.SLDPRT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]
2020-09-09 small fixes in joystick.py
    [joystick.py]
2020-09-09 Battery holder updated
    [Крепление батареек.SLDPRT, Крепление батареек.STL]
2020-09-10 Small blueprint fix
    [Полоска.SLDPRT, Полоска.STL]
2020-09-11 fixes, CS not working!
    [wheel_control.c]
2020-09-15 smth strange with wheel controller
2020-09-17 wheel CS - fixed, quite a bit of code modifications
    [common.h, lld_control.c, odometry.c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]
2020-09-17 Robot odometry without joystick - cheecked!
2020-09-18 fix tests with joystick, add time_k to robot_odometry (angle integral)
    [common.h, main.c]
2020-09-22 remove leds from stm-code
2020-09-24 Gyro start-up madness fixed
2020-11-05 raspberry side of logging
2020-11-13 Fixed logger time format. Added wait until.
    [joystick.py]
2021-04-23 tcp matlab side
    [platform.STL]
2021-04-23 tcp client raspberry side. Update logger
2021-06-01 Ball test fails, gyroscope slight fix
    [common.h]
2021-06-24 Tcp switch button
2021-07-27 Live test. Minor bugs fixed
    [utils.py, wireless_control.py]
2021-07-28 Clean up some big fixes
    [utils.py, wireless_control.py]
2022-07-09 EXT driver changed to pal. Minor differences fixed
    [lld_encoder.c, mcuconf.h, odometry.c]
